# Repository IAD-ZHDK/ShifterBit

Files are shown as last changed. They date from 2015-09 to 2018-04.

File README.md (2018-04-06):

# Shifter Bit

**A [littleBits](http://littlebits.cc) compatible module that connects to [shiftr.io](https://shiftr.io).**

Multiple ShifterBits

## Parts

- [ESP8266 Breakout](http://www.mouser.ch/ProductDetail/Adafruit/2471/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)
- [SD Card Holder](http://www.mouser.ch/ProductDetail/Molex/47352-1001/?qs=sGAEpiMZZMuJakaoiLiBpqoYXsE4YrD3r%2fU0grh%2fJ8Q%3d)
- [MCP41010](http://ww1.microchip.com/downloads/en/DeviceDoc/11195c.pdf)
- SD Card & Adapter

## Useful Links

- [Little Bits Eagle Templates](https://github.com/littleBitsbitLab/HDK-eagle-templates-libraries)
- [SD Card Holder Eagle Part](http://www.eaglecentral.ca/forums/index.php?t=msg&th=48291&start=0&e7001add2d4226236598bac9739173f3)
- [ESP8266 Breakout Info](https://learn.adafruit.com/adafruit-huzzah-esp8266-breakout/overview)

## Configuration

To configure the bit, edit the `/config.txt` on the SD card:

```
# Wifi Config
wifi_ssid: MY_WIFI
wifi_key: hidden_secret

# MQTT Config
mqtt_broker: broker.shiftr.io
mqtt_user: try
mqtt_password: try
mqtt_client_id: bit1

# Publish & Subscribe
# set to '-' to disable
publish_topic: data
subscribe_topic: -

# Uncomment to enable JSON
# use_json
```

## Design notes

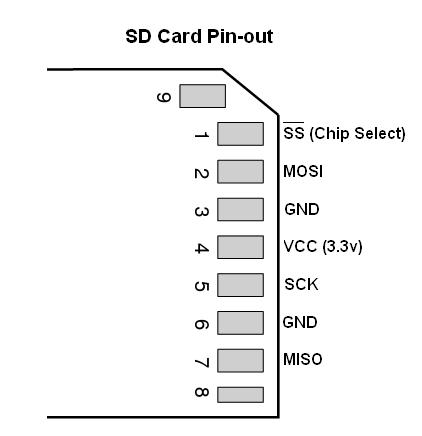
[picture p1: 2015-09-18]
Resources/sd_pinout.jpg

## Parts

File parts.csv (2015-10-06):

Name | Type | Qty | Shop | Link | Stock
ESP 8266 | Adafruit HUZZAH | 16 | Mouser | http://www.mouser.ch/ProductDetail/Adafruit/2471/?qs=GURawfaeGuAoxPWz4nSJYg%3d%3d | 16
microSD Card Holder | 47352-1001 | 16 | Farnell | http://ch.farnell.com/molex/4735-21001/steckplatz-micro-sd-8-positionen/dp/2424133 | 9 | 7
Digital Potentiometer | MCP41010-I/SN | 16 | Farnell | http://ch.farnell.com/microchip/mcp41010-i-sn/digital-pot-spi-10k-41010-soic8/dp/9758607 | 16
microSD Card + Adapter |  | 16 |  | http://www.distrelec.ch/en/microsd-card-class-10-gb-sp008gbsth010v10sp/p/30019831 |  | 16
56 Resistor | RC1206FR-0756RL | 32 |  |  | 32
1M Resistor |  | 16 |  |  | 16
1x10 Pinsockets | 2212S-10SG-85 | 32 | Farnell | http://ch.farnell.com/multicomp/2212s-10sg-85/buchse-lpt-1-reih-10kont/dp/1593464?ost=2212S-10SG-85 | 32
3K3 Resistor |  | 16 |  |  | 16
820 Resistor |  | 16 |  |  | 16
Green LED |  | 32 |  |  | 32
Pair of bitsnaps |  | 16 | littlebits | https://littlebits.cc/accessories/bitsnaps | 16

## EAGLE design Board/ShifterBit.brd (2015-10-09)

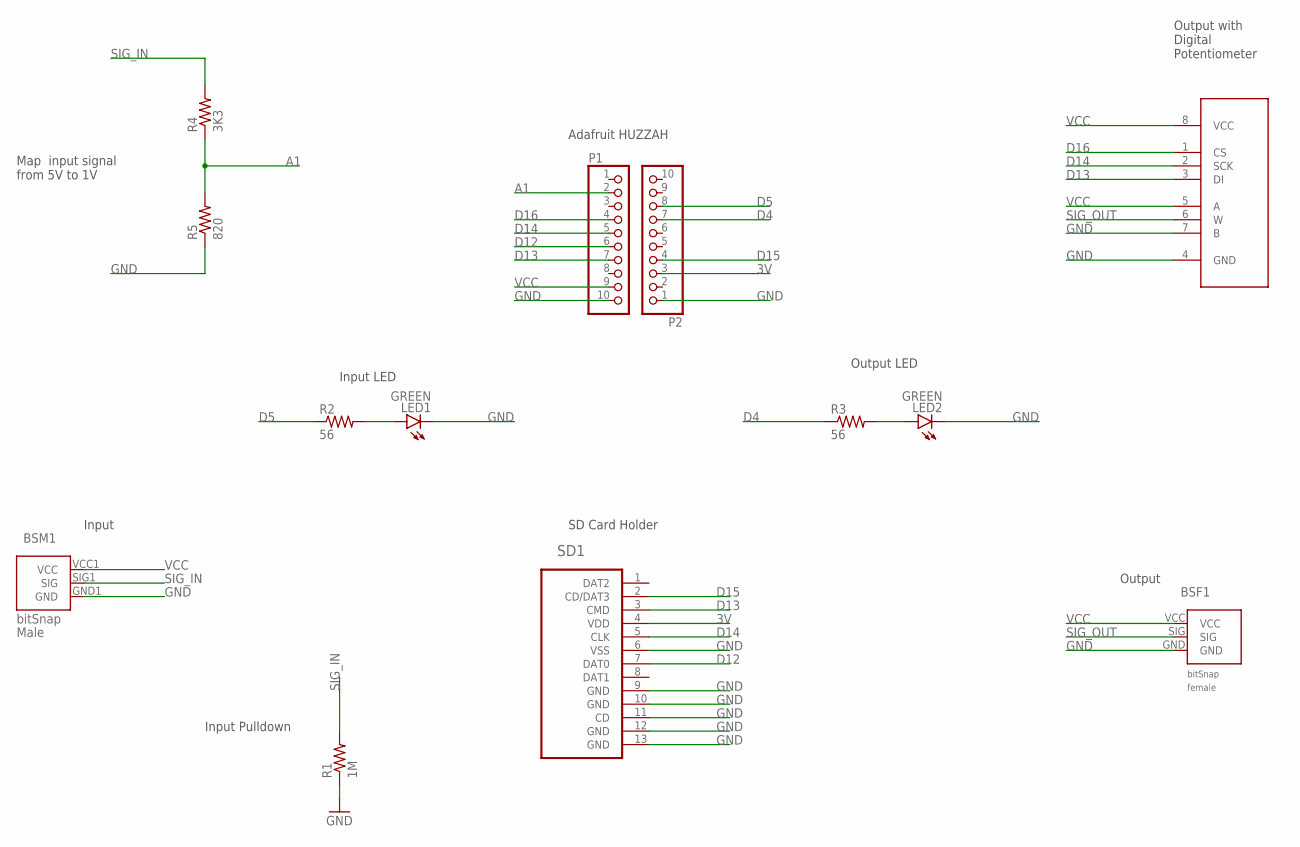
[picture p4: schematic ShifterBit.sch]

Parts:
BSF1: BITSNAP_V03_FEMALE
BSM1: BITSNAP_V03_MALE
DPOT1: MCP41XXX; SO08
LED1, LED2: GREEN; LED-1206
P1, P2: PINHD-1X10; 1X10-BIG
R1: 1M; RES-1206
R2, R3: 56; 1206
R4: 3K3; 1206
R5: 820; 1206
SD1: HIROSE_DM3CS-SF

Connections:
3V: P2.3, SD1.4 (VDD)
A1: P1.2, R4.1, R5.2
D4: P2.7, R3.1
D5: P2.8, R2.1
D12: P1.6, SD1.7 (DAT0)
D13: DPOT1.3 (DI), P1.7, SD1.3 (CMD)
D14: DPOT1.2 (SCK), P1.5, SD1.5 (CLK)
D15: P2.4, SD1.2 (CD/DAT3)
D16: DPOT1.1 (CS), P1.4
GND: BSF1.GND, BSM1.GND1 (GND), DPOT1.4 (GND), DPOT1.7 (B), LED1.C, LED2.C, P1.10, P2.1, R1.1, R5.1, SD1.6 (VSS), SD1.9 (GND), SD1.10 (GND), SD1.11 (CD), SD1.12 (GND), SD1.13 (GND)
unnamed: LED1.A, R2.2
unnamed: LED2.A, R3.2
SIG_IN: BSM1.SIG1 (SIG), R1.2, R4.2
SIG_OUT: BSF1.SIG, DPOT1.6 (W)
VCC: BSF1.VCC, BSM1.VCC1 (VCC), DPOT1.5 (A), DPOT1.8 (VCC), P1.9

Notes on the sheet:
Map input signal from 5V to 1V
Input LED
Output LED
Input Pulldown
Adafruit HUZZAH
SD Card Holder
Input
Output
Output with Digital Potentiometer

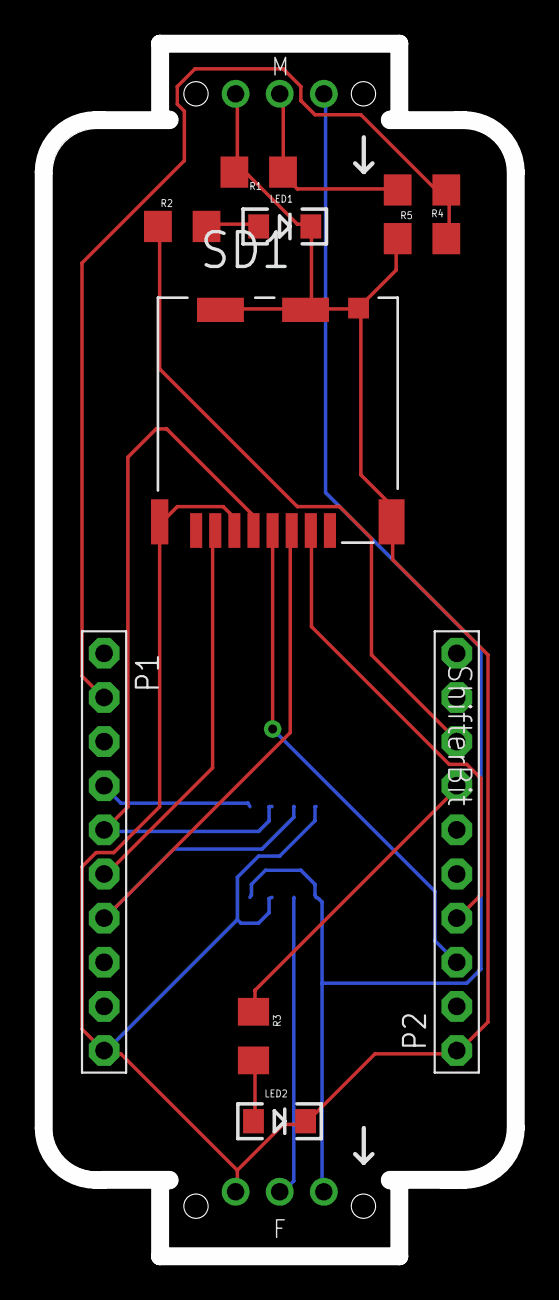
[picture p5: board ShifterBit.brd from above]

Board: 2 copper layers, 27.2 x 69.8 mm, 13 parts (1 on the bottom side), 15 nets.

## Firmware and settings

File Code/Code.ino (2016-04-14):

// predefine functions
void display_setup();
void display_set(int, int);
void wifi_setup();
void mqtt_setup();
void input_setup();
void output_setup();
void mqtt_loop();
void input_loop();
void display_loop();

void setup() {
  Serial.begin(9600);
  Serial.println("\nStarting...");

  display_setup();

  display_set(HIGH, LOW);
  config_setup();
  config_print();

  display_set(HIGH, HIGH);
  wifi_setup();
  mqtt_setup();
  
  display_set(LOW, LOW); 
  input_setup();
  output_setup();
}

void loop() {
  mqtt_loop();
  input_loop();
  display_loop();
}

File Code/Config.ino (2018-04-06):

/*
 * Config
 * 
 * Read config gile on attache SD card.
 * Pins: 14 (SCK), 12 (MISO), 13 (MOSI), 15 (SS)
 */

#include <SPI.h>
#include <SD.h>

#define CONFIG_SS_PIN 15
#define CONFIG_FILE "config.txt"

char config_wifi_ssid[64] = "";
char config_wifi_key[64] = "";
char config_mqtt_broker[64] = "";
char config_mqtt_user[64] = "";
char config_mqtt_password[64] = "";
char config_mqtt_client_id[64] = "";
bool config_publish = false;
char config_publish_topic[64] = "";
bool config_subscribe = false;
char config_subscribe_topic[64] = "";
bool config_json = false;

const char * _config_ws = "wifi_ssid: ";
const char * _config_wk = "wifi_key: ";
const char * _config_mb = "mqtt_broker: ";
const char * _config_cu = "mqtt_user: ";
const char * _config_cp = "mqtt_password: ";
const char * _config_ci = "mqtt_client_id: ";
const char * _config_pt = "publish_topic: ";
const char * _config_st = "subscribe_topic: ";
const char * _config_js = "use_json";

void config_setup() {
  SPI.begin();
  SD.begin(CONFIG_SS_PIN);

  Serial.println("Read Config...");
  
  File fd = SD.open(CONFIG_FILE, FILE_READ);
  while(fd.available() > 0) {
    config_read_line(fd.readStringUntil('\n'));
  }
  fd.close();

  SPI.end();
}

void config_read_line(String c) {
  int colon = c.indexOf(": ");

   if (c.startsWith(_config_ws)) {
     c.substring(colon + 2).toCharArray(config_wifi_ssid, 64);
   } else if (c.startsWith(_config_wk)) {
     c.substring(colon + 2).toCharArray(config_wifi_key, 64);
   } else if (c.startsWith(_config_mb)) {
     c.substring(colon + 2).toCharArray(config_mqtt_broker, 64);
   } else if (c.startsWith(_config_cu)) {
     c.substring(colon + 2).toCharArray(config_mqtt_user, 64);
   } else if(c.startsWith(_config_cp)) {
     c.substring(colon + 2).toCharArray(config_mqtt_password, 64);
   } else if(c.startsWith(_config_ci)) {
     c.substring(colon + 2).toCharArray(config_mqtt_client_id, 64);
   } else if(c.startsWith(_config_pt)) {
     String p = c.substring(colon + 2);
     p.toCharArray(config_publish_topic, 64);
     config_publish = !p.equals("-");
   } else if(c.startsWith(_config_st)) {
     String s = c.substring(colon + 2);
     s.toCharArray(config_subscribe_topic, 64);
     config_subscribe = !s.equals("-");
   } else if(c.startsWith(_config_js)) {
      config_json = true;
   }
}

void config_print() {
  Serial.print(_config_ws);
  Serial.println(config_wifi_ssid);
  Serial.print(_config_wk);
  Serial.println(config_wifi_key);
  Serial.print(_config_mb);
  Serial.println(config_mqtt_broker);
  Serial.print(_config_cu);
  Serial.println(config_mqtt_user);
  Serial.print(_config_cp);
  Serial.println(config_mqtt_password);
  Serial.print(_config_ci);
  Serial.println(config_mqtt_client_id);
  Serial.print(_config_pt);
  Serial.println(config_publish_topic);
  Serial.print(_config_st);
  Serial.println(config_subscribe_topic);

  if(config_json) {
    Serial.println("json enabled");
  } else {
    Serial.println("json disabled");
  }
}

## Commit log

2015-09-16 added Arduino test code
2015-09-17 added first board layout test
    [ShifterBit2.brd, ShifterBit2.sch]
2015-09-18 removed esd protection
    [ShifterBit2.brd, ShifterBit2.sch]
2015-09-20 added nets and leds
    [ShifterBit2.brd, ShifterBit2.sch]
2015-09-21 renamed and added voltage divider for signal input
    [ShifterBit.brd, ShifterBit.sch]
2015-09-22 added transistor and some labels
    [ShifterBit.brd, ShifterBit.sch]
2015-09-22 added resistor to dac
    [ShifterBit.brd, ShifterBit.sch]
2015-09-26 connected the sd card
    [ShifterBit.brd, ShifterBit.sch]
2015-09-26 changed resistor name
    [ShifterBit.brd, ShifterBit.sch]
2015-09-27 fix pwm stuff
2015-09-27 added component to board
    [ShifterBit.brd, ShifterBit.sch]
2015-09-27 made board longer and placed all components on top
    [ShifterBit.brd]
2015-09-27 better placement
    [ShifterBit.brd]
2015-09-27 prepared digi pot SPi
2015-09-30 corrected milling path
    [ShifterBit.brd]
2015-09-30 corrected socket position
    [ShifterBit.brd]
2015-09-30 added some aesthetics
    [ShifterBit.brd, ShifterBit.sch]
2015-09-30 renamed signal
    [ShifterBit.brd, ShifterBit.sch]
2015-09-30 removed unused nets
    [ShifterBit.brd, ShifterBit.sch]
2015-09-30 repositioned elements
    [ShifterBit.brd]
2015-09-30 load sparkfun design rules and auto route
    [ShifterBit.brd]
2015-09-30 grounded cd
    [ShifterBit.brd, ShifterBit.sch]
2015-09-30 use 1206 packages
    [ShifterBit.brd, ShifterBit.sch]
2015-10-01 added parts list
    [parts.csv]
2015-10-06 updated orders
    [parts.csv]
2015-10-09 fixed missing connection
    [ShifterBit.brd, ShifterBit.sch]
2015-10-09 switched pins
2015-10-09 added sample config
    [config.txt]
2015-10-11 update client id
    [config.txt]
2018-04-06 added missing callback config
    [Connection.ino]

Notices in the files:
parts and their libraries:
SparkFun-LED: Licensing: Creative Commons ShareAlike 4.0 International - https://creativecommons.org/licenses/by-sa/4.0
